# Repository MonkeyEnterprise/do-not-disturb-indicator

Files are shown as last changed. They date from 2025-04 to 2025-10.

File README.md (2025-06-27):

<!-- PROJECT LOGO -->
<div align="center">
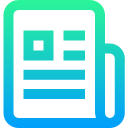
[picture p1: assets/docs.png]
    
<h3 align="center">00.25.0029 - Do Not Disturb Indicator</h3>
</div>
<!-- ABOUT THE PROJECT -->

### About The Project

---

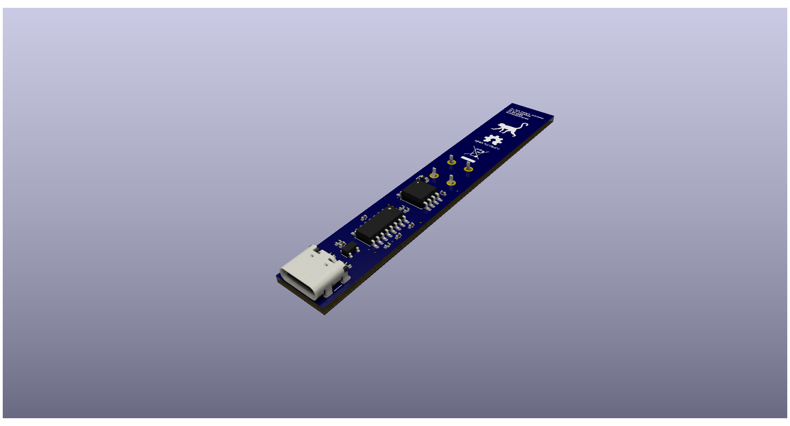
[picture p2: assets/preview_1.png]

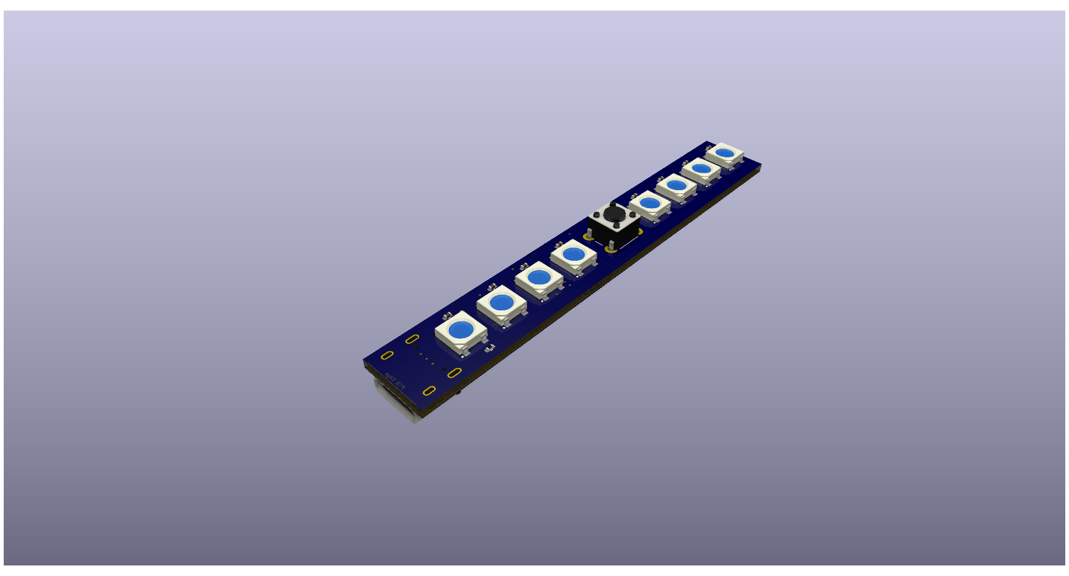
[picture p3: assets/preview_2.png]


This repository provides a comprehensive system to control an WS2812B LED using an ATTINY-85. It includes PCB files, 3D print files, firmware, and software for setting up and operating the system. The firmware implements a serial communication protocol for sending color and brightness commands to the WS2812B LED, using a packet structure with error-checking mechanisms. This setup allows for easy integration and customization of the do not disturb sign.

<!-- BUILD WITH -->
### Built With

* 
* 
* 
* 

<!-- LICENSE -->
### License

---
See `LICENSE` for more information.

<!-- MARKDOWN LINKS & IMAGES -->
<!-- https://www.markdownguide.org/basic-syntax/#reference-style-links -->
[KiCad]: https://img.shields.io/badge/KiCad-3F7D1F?style=for-the-badge&logoColor=white&labelColor=3F7D1F
[VSCode]: https://img.shields.io/badge/VSCode-007ACC?style=for-the-badge&logoColor=white&labelColor=007ACC
[Visual Studio]: https://img.shields.io/badge/Visual_Studio-5C2D91?style=for-the-badge&logoColor=white&labelColor=5C2D91
[SimulIDE]: https://img.shields.io/badge/SimulIDE-0094B3?style=for-the-badge&logoColor=white&labelColor=0094B3

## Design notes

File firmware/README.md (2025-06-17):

# Serial Protocol Documentation

This document describes the serial protocol used to communicate with the NeoPixel controller firmware (`Main.cpp`). The protocol is designed for robust communication, including error checking via CRC, and supports commands for setting colors, changing modes, and querying the current state.

## Protocol Structure

Each command sent to the device must be **9 bytes** long and follow this structure:

| Byte Index | Name | Description | Value Range |
|---|---|---|---|
| 0 | SOF | Start of Frame | `0x01` |
| 1 | Command | Command code (comc) | `0x01` - `0x05`  |
| 2 | Command Val  | Command value (comv), e.g. mode | `0x00` - `0x02`  |
| 3 | Red | Red component | `0x00` - `0xFF`  |
| 4 | Green | Green component | `0x00` - `0xFF`  |
| 5 | Blue | Blue component | `0x00` - `0xFF`  |
| 6 | Brightness | Brightness | `0x00` - `0xFF`  |
| 7 | CRC | Checksum: sum of bytes 1-6, modulo 256 | |
| 8 | EOF | End of Frame | `0x01` |

**CRC Calculation:**  
`CRC = (Command + Command Val + Red + Green + Blue + Brightness) % 256`

## Command Codes

| Code | Name | Description |
|---|---|---|
| 0x01 | Set Color | Set the current color and brightness |
| 0x02 | Clear | Clear the LED strip |
| 0x03 | Set Mode | Change the active mode (0, 1, or 2) |
| 0x04 | Store Color  | Store color and brightness for current mode |
| 0x05 | Get Color | Query the current color and brightness |

## Example Commands

### 1. Set Color (Red, mode 0, brightness 255)

- **Command:** Set color to red, mode 0, brightness 255  
- **Fields:** SOF=01, Command=01, Command Val=00, R=FF, G=00, B=00, Brightness=FF  
- **CRC:** (01 + 00 + FF + 00 + 00 + FF) % 256 = 0x01 + 0x00 + 0xFF + 0x00 + 0x00 + 0xFF = 0x1FF, 0x1FF % 256 = 0xFF  
- **Bytes:** `01 01 00 FF 00 00 FF FF 01`

### 2. Store Color (Green, mode 1, brightness 128)

- **Command:** Store color green for mode 1, brightness 128  
- **Fields:** SOF=01, Command=04, Command Val=01, R=00, G=FF, B=00, Brightness=80  
- **CRC:** (04 + 01 + 00 + FF + 00 + 80) % 256 = 0x184, 0x184 % 256 = 0x84  
- **Bytes:** `01 04 01 00 FF 00 80 84 01`

### 3. Set Mode (mode 2)

- **Command:** Set mode to 2  
- **Fields:** SOF=01, Command=03, Command Val=02, R=00, G=00, B=00, Brightness=00  
- **CRC:** (03 + 02 + 00 + 00 + 00 + 00) % 256 = 0x05  
- **Bytes:** `01 03 02 00 00 00 00 05 01`

### 4. Get Color (for current mode)

- **Command:** Get color for current mode  
- **Fields:** SOF=01, Command=05, Command Val=00, R=00, G=00, B=00, Brightness=00  
- **CRC:** (05 + 00 + 00 + 00 + 00 + 00) % 256 = 0x05  
- **Bytes:** `01 05 00 00 00 00 00 05 01`

### 5. Clear LEDs

- **Command:** Clear the LED strip  
- **Fields:** SOF=01, Command=02, Command Val=00, R=00, G=00, B=00, Brightness=00  
- **CRC:** (02 + 00 + 00 + 00 + 00 + 00) % 256 = 0x02  
- **Bytes:** `01 02 00 00 00 00 00 02 01`

## Error Codes

The device responds with a response code indicating the result:

| Code | Meaning |
|---|---|
| 0x0  | Success |
| 0x1  | Start of Frame error |
| 0x2  | Command error |
| 0x3  | Command value error |
| 0x4  | CRC error |
| 0x5  | End of Frame error |

---

For more details, see the implementation in `Main.cpp`.

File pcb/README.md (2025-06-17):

This directory is intended for the project pcb.

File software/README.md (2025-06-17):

# NeoPixel Status Tray Application

A Windows system tray application for controlling a NeoPixel device via serial port.  
Easily set your status (Do Not Disturb, Busy, Available, Off), adjust brightness, and customize colors.

## Features

- System tray icon with status indicator
- Selectable statuses: Do Not Disturb, Busy, Available, Off
- Adjustable brightness (Dimmer, Normal, Brighter)
- Custom color picker for each status
- COM port selection menu
- Settings saved to `settings.json`
- Logging to `main.log` and console

## Requirements

- Python 3.13+
- [pyserial](https://pypi.org/project/pyserial/)
- [pystray](https://pypi.org/project/pystray/)
- [Pillow](https://pypi.org/project/Pillow/)

Install dependencies with:

```sh
pip install -r requirements.txt
```

## Usage

1. Connect your NeoPixel device to a serial port.
2. Run the application:
3. Use the tray icon to select your COM port and control the device.

## Project Structure

- `main.py` — Application entry point
- `source/toolbar_menu.py` — Main tray menu logic
- `source/serial_controller.py` — Serial port communication
- `source/protocol.py` — Protocol for device commands
- `source/icon_creator.py` — Icon image generation
- `source/settings_manager.py` — Settings load/save logic

## Settings

Settings are stored in `settings.json` and include:

- Colors for each status
- Last used COM port
- Brightness factor

## Logging

Logs are written to `main.log` and the console for troubleshooting.

---

*Developed for NeoPixel status indication via system tray.*

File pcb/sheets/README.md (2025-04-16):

This directory is intended for the project pcb pages.

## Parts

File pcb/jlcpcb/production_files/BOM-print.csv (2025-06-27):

Comment | Designator | Footprint | LCSC | Quantity
PRTR5V0U2X | D1 | SOT-143 | C12333 | 1
100nF | C1,C10,C11,C12,C13,C2,C3,C4,C6,C7,C8,C9 | C_0402_1005Metric | C1525 | 12
4.7nF/1kV | C5 | C_0402_1005Metric | C1538 | 1
CPU | D2 | D_0603_1608Metric | C2286 | 1
1K0 | R1,R4,R5,R7 | R_0402_1005Metric | C25744 | 4
4K7 | R6 | R_0402_1005Metric | C25900 | 1
5K1 | R2,R3 | R_0402_1005Metric | C25905 | 2
1M0 | R8 | R_0402_1005Metric | C26083 | 1
USB_C_Receptacle_USB2.0_16P | J1 | USB_C_Receptacle_GCT_USB4105-xx-A_16P_TopMnt_Horizontal | C2765186 | 1
WS2812B | D10,D3,D4,D5,D6,D7,D8,D9 | LED_WS2812B_PLCC4_5.0x5.0mm_P3.2mm | C2843785 | 8
ATtiny85-20S | U1 | SOIC-8_5.3x5.3mm_P1.27mm | C31540447 | 1
CH340C | U2 | SOIC-16_3.9x9.9mm_P1.27mm | C84681 | 1

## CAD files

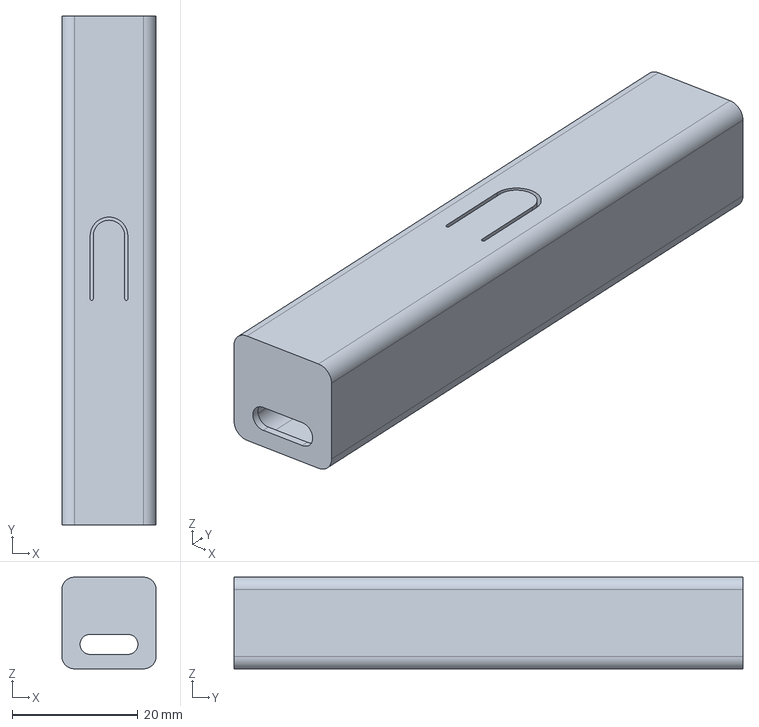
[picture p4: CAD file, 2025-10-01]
models/model.FCStd
15.0 x 81.0 x 14.6 mm

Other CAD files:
models/model.3mf
models/model.stl

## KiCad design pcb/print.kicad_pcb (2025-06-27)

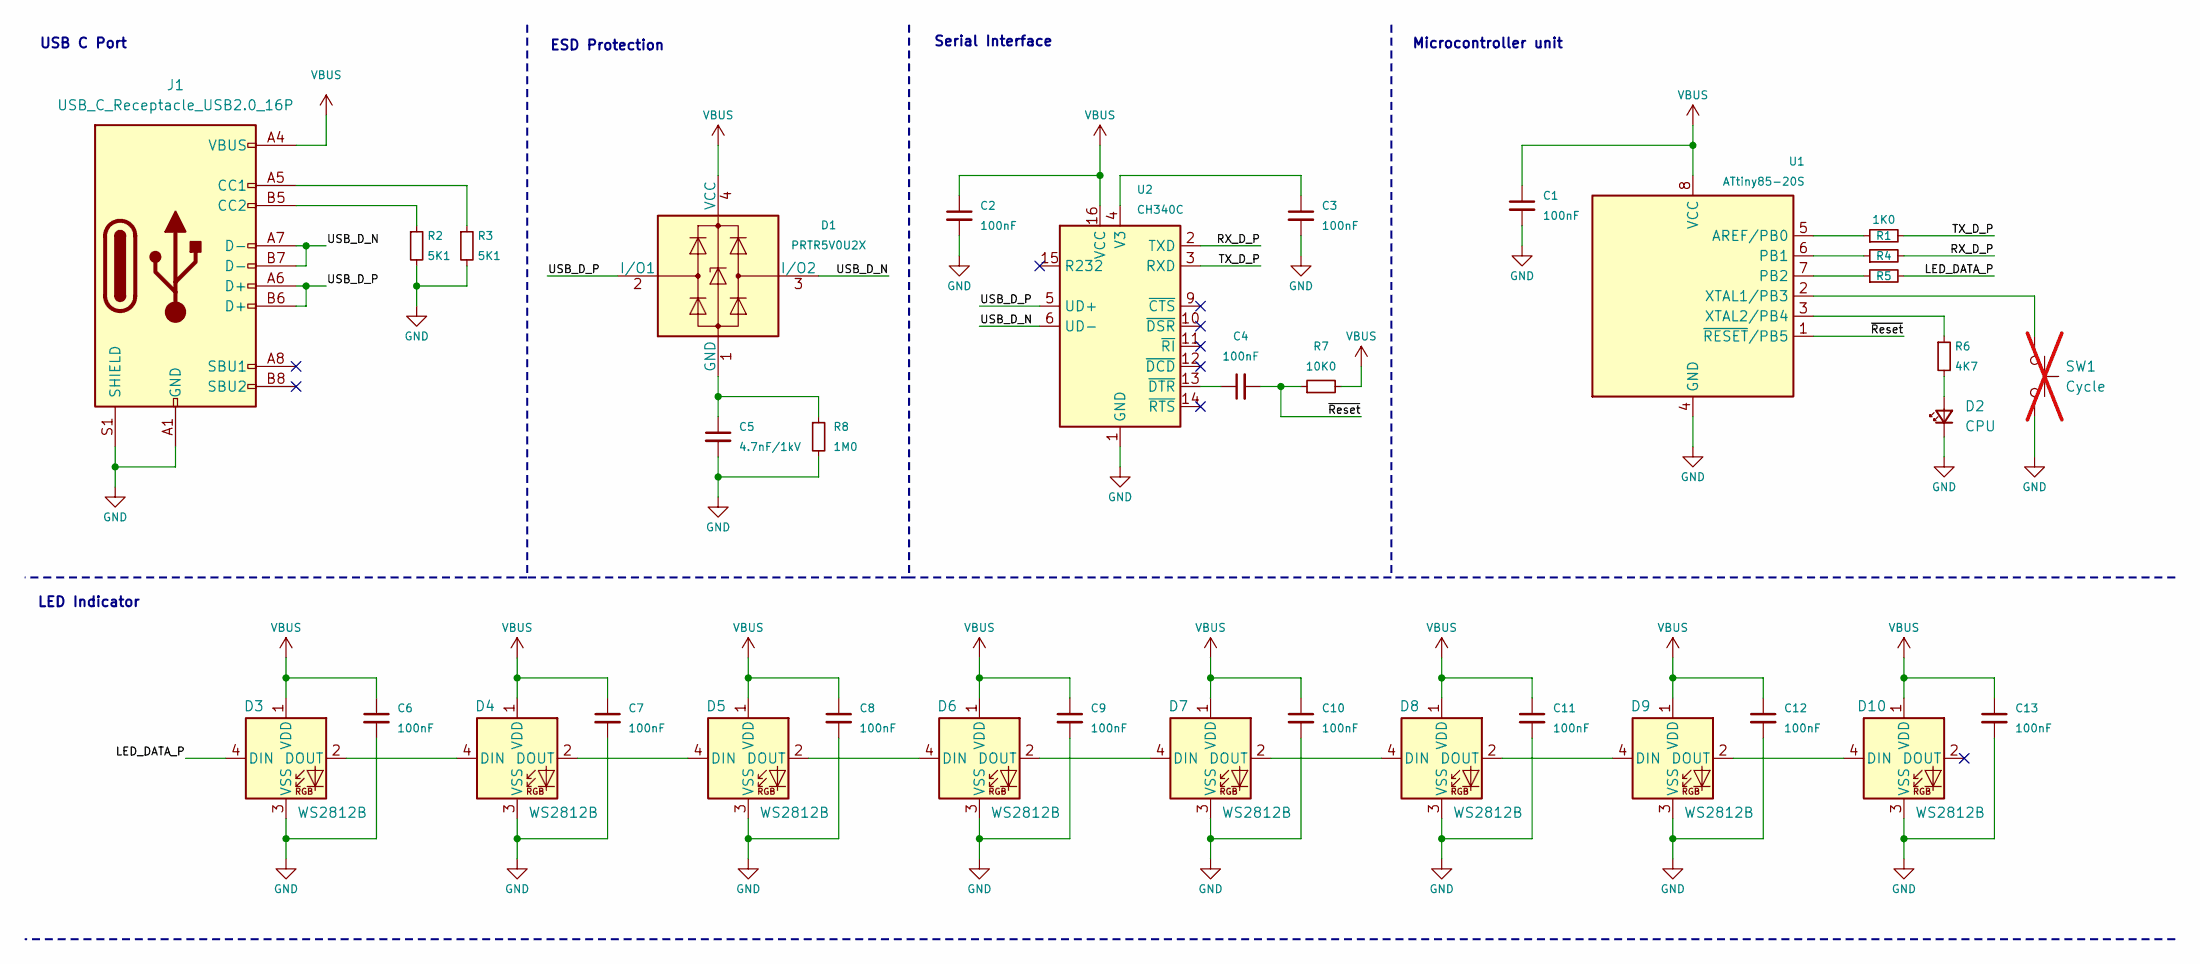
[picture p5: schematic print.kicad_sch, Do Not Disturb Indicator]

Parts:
C1, C2, C3, C4, C6, C7, C8, C9, C10, C11, C12, C13: 100nF; C_0402_1005Metric; LCSC C1525
C5: 4.7nF/1kV; C_0402_1005Metric; LCSC C1538
D1: PRTR5V0U2X; SOT-143; LCSC C12333
D2: CPU; D_0603_1608Metric; LCSC C2286
D3, D4, D5, D6, D7, D8, D9, D10: WS2812B; LED_WS2812B_PLCC4_5.0x5.0mm_P3.2mm; LCSC C2843785
J1: USB_C_Receptacle_USB2.0_16P; USB_C_Receptacle_GCT_USB4105-xx-A_16P_TopMnt_Horizontal; LCSC C2765186
R1, R4, R5: 1K0; R_0402_1005Metric; LCSC C25744
R2, R3: 5K1; R_0402_1005Metric; LCSC C25905
R6: 4K7; R_0402_1005Metric; LCSC C25900
R7: 10K0; R_0402_1005Metric; LCSC C25744
R8: 1M0; R_0402_1005Metric; LCSC C26083
SW1: Cycle; SW_PUSH_6mm_H4.3mm; not fitted
U1: ATtiny85-20S; SOIC-8_5.3x5.3mm_P1.27mm; LCSC C31540447
U2: CH340C; SOIC-16_3.9x9.9mm_P1.27mm; LCSC C84681

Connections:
/LED_DATA_P: D3.4 (DIN), R5.2
/RX_D_P: R4.2, U2.2 (TXD)
/TX_D_P: R1.2, U2.3 (RXD)
/USB_D_N: D1.3 (I/O2), J1.A7 (D-), J1.B7 (D-), U2.6 (UD-)
/USB_D_P: D1.2 (I/O1), J1.A6 (D+), J1.B6 (D+), U2.5 (UD+)
/~Reset: C4.2, R7.1, U1.1 (~RESET/PB5)
GND: C1.2, C2.2, C3.2, C5.2, C6.2, C7.2, C8.2, C9.2, C10.2, C11.2, C12.2, C13.2, D2.1 (K), D3.3 (VSS), D4.3 (VSS), D5.3 (VSS), D6.3 (VSS), D7.3 (VSS), D8.3 (VSS), D9.3 (VSS), D10.3 (VSS), J1.A1 (GND), J1.A12 (GND), J1.B1 (GND), J1.B12 (GND), J1.S1 (SHIELD), R2.2, R3.2, R8.2, SW1.2, U1.4 (GND), U2.1 (GND)
unnamed: C5.1, D1.1 (GND), R8.1
unnamed: D2.2 (A), R6.2
unnamed: D3.2 (DOUT), D4.4 (DIN)
unnamed: D4.2 (DOUT), D5.4 (DIN)
unnamed: D5.2 (DOUT), D6.4 (DIN)
unnamed: D6.2 (DOUT), D7.4 (DIN)
unnamed: D7.2 (DOUT), D8.4 (DIN)
unnamed: D8.2 (DOUT), D9.4 (DIN)
unnamed: D9.2 (DOUT), D10.4 (DIN)
unnamed: J1.A5 (CC1), R3.1
unnamed: J1.B5 (CC2), R2.1
unnamed: R1.1, U1.5 (AREF/PB0)
unnamed: R4.1, U1.6 (PB1)
unnamed: R5.1, U1.7 (PB2)
unnamed: SW1.1, U1.2 (XTAL1/PB3)
unnamed: R6.1, U1.3 (XTAL2/PB4)
unnamed: C3.1, U2.4 (V3)
unnamed: C4.1, U2.13 (~DTR)
VBUS: C1.1, C2.1, C6.1, C7.1, C8.1, C9.1, C10.1, C11.1, C12.1, C13.1, D1.4 (VCC), D3.1 (VDD), D4.1 (VDD), D5.1 (VDD), D6.1 (VDD), D7.1 (VDD), D8.1 (VDD), D9.1 (VDD), D10.1 (VDD), J1.A4 (VBUS), J1.A9 (VBUS), J1.B4 (VBUS), J1.B9 (VBUS), R7.2, U1.8 (VCC), U2.16 (VCC)

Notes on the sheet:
USB C Port
Microcontroller unit
Serial Interface
LED Indicator
ESD Protection

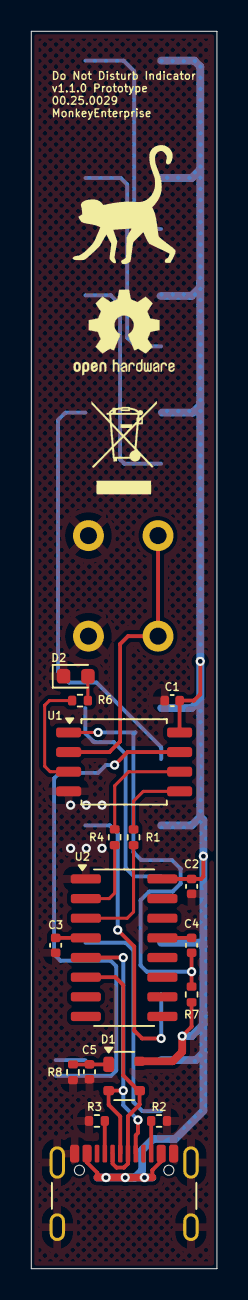
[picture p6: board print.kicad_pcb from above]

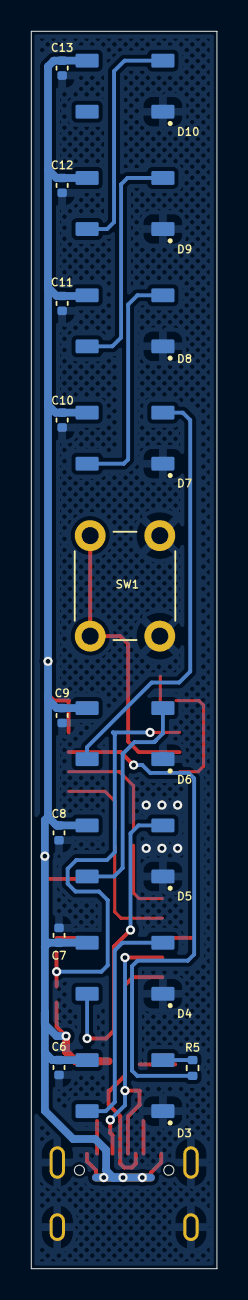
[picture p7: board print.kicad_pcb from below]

Board: 2 copper layers, 12.0 x 80.0 mm, 35 parts (18 on the bottom side), 26 nets.

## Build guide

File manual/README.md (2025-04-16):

This directory is intended for the project manual.

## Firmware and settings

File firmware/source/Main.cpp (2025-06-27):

/**
 * @file Main.cpp
 * @brief Main source file for the device firmware.
 *
 * @copyright (c) 2025 Lorenzo Pouw, PouwerTronics/MonkeyEnterprise.
 * Licensed under the BSD license. This notice must remain in all redistributions.
 */

#include "Main.h"

/**
 * @brief Get the RGB color and brightness values based on the current mode
 * @param red Reference to store the red component (0-255)
 * @param green Reference to store the green component (0-255)
 * @param blue Reference to store the blue component (0-255)
 * @param brightness Reference to store the brightness (0-255)
 */
void getColor(uint8_t &red, uint8_t &green, uint8_t &blue, uint8_t &brightness)
{
    // Define a structure to hold the color reference based on the current mode
    struct ColorRef
    {
        uint8_t &r, &g, &b, &br;
    };

    // Lambda function to get the current color reference based on the mode
    auto getColorRef = [&]() -> ColorRef
    {
        switch (globalVar.mode)
        {
        case 0:
            return {globalVar.red_mode0, globalVar.green_mode0, globalVar.blue_mode0, globalVar.brightness_mode0};
        case 1:
            return {globalVar.red_mode1, globalVar.green_mode1, globalVar.blue_mode1, globalVar.brightness_mode1};
        case 2:
            return {globalVar.red_mode2, globalVar.green_mode2, globalVar.blue_mode2, globalVar.brightness_mode2};
        default:
            return {globalVar.red_mode0, globalVar.green_mode0, globalVar.blue_mode0, globalVar.brightness_mode0};
        }
    };

    // Get the current color based on the mode
    ColorRef color = getColorRef();

    red = color.r;
    green = color.g;
    blue = color.b;
    brightness = color.br;
}

/**
 * @brief Store the RGB color and brightness values in the global variable based on the current mode
 * @param red The red component of the color (0-255)
 * @param green The green component of the color (0-255)
 * @param blue The blue component of the color (0-255)
 * @param brightness The brightness of the color (0-255)
 */
void storeColor(uint8_t red, uint8_t green, uint8_t blue, uint8_t brightness)
{
    switch (globalVar.mode)
    {
    case 0:
        globalVar.red_mode0 = red;
        globalVar.green_mode0 = green;
        globalVar.blue_mode0 = blue;
        globalVar.brightness_mode0 = brightness;
        break;
    case 1:
        globalVar.red_mode1 = red;
        globalVar.green_mode1 = green;
        globalVar.blue_mode1 = blue;
        globalVar.brightness_mode1 = brightness;
        break;
    case 2:
        globalVar.red_mode2 = red;
        globalVar.green_mode2 = green;
        globalVar.blue_mode2 = blue;
        globalVar.brightness_mode2 = brightness;
        break;
    default:
        break;
    };

    cfgReg.save(globalVar);
}

/**
 * @brief Set the color of the NeoPixel LEDs based on the current mode
 */
void setColor()
{
    uint8_t red, green, blue, brightness;
    getColor(red, green, blue, brightness);
    pixel.setBrightness(brightness);
    pixel.fill(pixel.Color(red, green, blue));
    pixel.show();
}

/**
 * @brief Flush the receive buffer to clear any pending data
 */
void flushReceiveBuffer()
{
    // Flush the receive buffer to clear any pending data
    while (tinySerial.available())
    {
        tinySerial.read();
    }
}

/**
 * @brief Send a response back to the serial interface, including a CRC for error checking
 * @param responseCode The response code to be sent.
 * @param comc The command value (comc) to be sent (0-255), optional, default is 0x0.
 * @param red The red component of the color to be sent (0-255), optional, default is 0x0.
 * @param green The green component of the color to be sent (0-255), optional, default is 0x0.
 * @param blue The blue component of the color to be sent (0-255), optional, default is 0x0.
 * @param brightness The brightness of the color to be sent (0-255), optional, default is 0x0.
 */
void sendResponse(const uint8_t responseCode,
                  const uint8_t comc = 0x0,
                  const uint8_t red = 0x0,
                  const uint8_t green = 0x0,
                  const uint8_t blue = 0x0,
                  const uint8_t brightness = 0x0)
{
    uint8_t crc = (responseCode + comc + red + green + blue + brightness) % 256;
    tinySerial.write(0x01);         // Start of Frame
    tinySerial.write(responseCode); // Response code
    tinySerial.write(comc);         // Command value (comc)
    tinySerial.write(red);          // Red component
    tinySerial.write(green);        // Green component
    tinySerial.write(blue);         // Blue component
    tinySerial.write(brightness);   // Brightness
    tinySerial.write(crc);          // CRC
    tinySerial.write(0x01);         // End of Frame
    tinySerial.flush();             // Ensure all data is sent
    flushReceiveBuffer(); // Clear the receive buffer after sending
}

/**
 * @brief Handle the command received from the serial interface
 * @param data Pointer to the command data
 * @return Response code indicating success or error
 *
 * @note The error codes are as follows:
 * 0x0 - Success
 * 0x1 - Start of Frame (SOF) error
 * 0x2 - Command (coma) error
 * 0x3 - Command value (comc) error
 * 0x4 - CRC error
 * 0x5 - End of Frame (EOF) error
 */
uint8_t handleCommand(const uint8_t *data)
{
    // Check if the start of frame (SOF) is correct and validate the command structure
    const uint8_t sof = data[0];
    if (sof != 0x1)
        return 0x1;

    // Validate the command (coma), which should be between 1 and 5
    const uint8_t coma = data[1];
    if (coma > 5)
        return 0x2;

    // Validate the command value (comc), which should be between 0 and 2
    const uint8_t comc = data[2];
    if (comc > 2)
        return 0x3;

    // Validate the RGB color components and brightness
    const uint8_t red = data[3];
    const uint8_t green = data[4];
    const uint8_t blue = data[5];
    const uint8_t brightness = data[6];

    // validate the CRC calculation
    const uint8_t crc = data[7];
    const uint8_t crcCalc = (coma + comc + red + green + blue + brightness) % 256;
    if (crc != crcCalc)
        return 0x4;

    // Check if the end of frame (EOF) is correct
    const uint8_t eof = data[8];
    if (eof != 0x1)
        return 0x5;

    // If all checks passed, return success
    return 0x0;
}

/**
 * @brief Setup function to initialize the serial communication, NeoPixel strip, and global variables
 */
void setup()
{
    // Initialize the serial communication with the specified baud rate
    tinySerial.begin(BAUD_RATE);

    flushReceiveBuffer();

    // Initialize the global variable with default configuration
    GlobalVar temp = cfgReg.load(defaultCfg);
    if (temp.config_version != defaultCfg.config_version)
    {
        globalVar = defaultCfg;
        cfgReg.wipeEEPROM();
        cfgReg.save(globalVar);
    }
    else
        globalVar = temp;

    // Initialize the pixel strip
    pixel.begin();
    setColor();
    cpuLed.enableBlink(500);
}

/**
 * @brief Main loop function that continuously checks for button presses and serial commands
 */
void loop()
{
    // Update the cycle button state and check if it was pressed
    cycleButton.update();
    if (cycleButton.fell())
    {
        globalVar.mode = (globalVar.mode + 1) % 3;
        cfgReg.save(globalVar);
        setColor();
    }

    // Check if there are enough bytes available in the serial buffer to read a command
    // The command should be 9 bytes long: SOF (1 byte) + coma (1 byte) + comc (1 byte) + RGB (3 bytes) + brightness (1 byte) + CRC (1 byte) + EOF (1 byte)
    // If there are enough bytes, read the command and handle it
    if (tinySerial.available() == 9)
    {
        uint8_t data[9];
        tinySerial.readBytes(data, 9);

        const uint8_t responseCode = handleCommand(data);

        if (responseCode == 0x0)
        {
            const uint8_t coma = data[1];
            const uint8_t comc = data[2];
            const uint8_t red = data[3];
            const uint8_t green = data[4];
            const uint8_t blue = data[5];
            const uint8_t brightness = data[6];

            switch (coma)
            {
            // Set color command
            case 0x01:
                setColor();
                sendResponse(0x0); // Success response
                break;
            // Clear the pixel strip
            case 0x02:
                pixel.clear();
                pixel.show();
                sendResponse(0x0); // Success response
                break;
            // Set mode command
            case 0x03:
                globalVar.mode = comc;
                cfgReg.save(globalVar);
                setColor();
                sendResponse(0x0); // Success response
                break;
            // Store color command
            case 0x04:
                storeColor(red, green, blue, brightness);
                sendResponse(0x0); // Success response
                break;
            // Get color command
            case 0x05:
                uint8_t cureRed, currentGreen, currentBlue, currentBrightness;
                getColor(cureRed, currentGreen, currentBlue, currentBrightness);
                sendResponse(0x0, globalVar.mode, cureRed, currentGreen, currentBlue, currentBrightness);
                break;
            // Invalid command, this should not happen, just in case send an error response
            default:
                sendResponse(0x2); // Invalid command
                break;
            }
        }
    }
    cpuLed.update();
}

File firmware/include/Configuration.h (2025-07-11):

/**
 * @file Configuration.h
 * @brief Configuration header file for the device firmware.
 *
 * @copyright (c) 2025 Lorenzo Pouw, PouwerTronics/MonkeyEnterprise.
 * Licensed under the BSD license. This notice must remain in all redistributions.
 */

#ifndef __CONFIGURATION_H__
#define __CONFIGURATION_H__

#include <Arduino.h>
#include <Adafruit_NeoPixel.h>

// Define the CPU frequency for the AVR microcontroller
// ------- Hardware Configuration -------
#define TX_PIN PB0
#define RX_PIN PB1
#define LED_PIN PB2
#define CPU_PIN PB4
#define BUTTON_PIN PB3

// ------- Software Configuration -------
#define BAUD_RATE 9600
#define LED_COUNT 8
#define LED_TYPE NEO_GRB + NEO_KHZ800

// ------- Global Variables -------
struct GlobalVar
{
    uint8_t config_version;
    uint8_t mode;
    uint8_t red_mode0, green_mode0, blue_mode0, brightness_mode0;
    uint8_t red_mode1, green_mode1, blue_mode1, brightness_mode1;
    uint8_t red_mode2, green_mode2, blue_mode2, brightness_mode2;
};

const GlobalVar defaultCfg = {
    1,               // config_version
    0,               // mode
    255, 0, 0, 255,  // mode 0: red, green, blue, brightness
    0, 255, 0, 255,  // mode 1: red, green, blue, brightness
    255, 255, 0, 255 // mode 2: red, green, blue, brightness
};

#endif // __CONFIGURATION_H__

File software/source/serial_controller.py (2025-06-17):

# software/source/serial_controller.py
import logging
import serial
import serial.tools.list_ports
from typing import List, Tuple, Optional

# Assuming Protocol is defined in ./protocol.py
from .protocol import Protocol 

class SerialController:
    """
    @brief Manages serial communication with a device.

    Handles port discovery, connection, disconnection, and sending commands.
    """

    def __init__(self, protocol: Protocol, baudrate: int):
        """
        @brief Initializes the SerialController.

        @param protocol: An instance of the Protocol class for command creation.
        @type protocol: Protocol
        @param baudrate: The baud rate for serial communication.
        @type baudrate: int
        """
        self._protocol = protocol
        self._baudrate = baudrate
        self._serial_port: Optional[serial.Serial] = None  # Holds the pyserial Serial object
        self._selected_port_device: Optional[str] = None # Stores the device name, e.g., 'COM3'

    @property
    def selected_port(self) -> Optional[str]:
        """
        @brief Get the currently selected COM port device name.

        @return: The selected COM port device name, or None if not set.
        @rtype: str | None
        """
        return self._selected_port_device

    @selected_port.setter
    def selected_port(self, port_device: Optional[str]) -> None:
        """
        @brief Set the COM port device name.

        Note: Setting this property does not automatically connect. Call connect() explicitly.

        @param port_device: The COM port device name (e.g., 'COM3', '/dev/ttyUSB0').
        @type port_device: str | None
        @return: None
        """
        self._selected_port_device = port_device

    @property
    def is_connected(self) -> bool:
        """
        @brief Checks if the serial port is currently open and connected.

        @return: True if connected, False otherwise.
        @rtype: bool
        """
        return self._serial_port is not None and self._serial_port.is_open

    def connect(self) -> bool:
        """
        @brief Attempts to open the selected serial port.

        If a port is already open, it will be closed first.
        Sets self._serial_port to the pyserial Serial object on success.

        @return: True if connection was successful, False otherwise.
        @rtype: bool
        """
        if self._serial_port and self._serial_port.is_open:
            self.close_port() # Ensure any existing open port is closed

        if not self._selected_port_device:
            logging.warning("No COM port selected to connect.")
            return False

        try:
            logging.info(f"Attempting to open serial port: {self._selected_port_device} at {self._baudrate} baud.")
            # Timeout for reading: set to a small value, e.g., 1 second
            self._serial_port = serial.Serial(self._selected_port_device, self._baudrate, timeout=1)
            # You might want to send a handshake command here and read a response
            # to verify the device is responsive.
            return True
        except serial.SerialException as e:
            logging.error(f"Could not open serial port {self._selected_port_device}: {e}")
            self._serial_port = None  # Ensure it's None on failure
            return False
        except Exception as e:
            logging.error(f"An unexpected error occurred during serial connection: {e}", exc_info=True)
            self._serial_port = None
            return False

    def close_port(self) -> None:
        """
        @brief Closes the currently open serial port, if any.

        @return: None
        """
        if self._serial_port and self._serial_port.is_open:
            logging.info(f"Closing serial port: {self._selected_port_device}")
            try:
                self._serial_port.close()
            except serial.SerialException as e:
                logging.error(f"Error closing serial port {self._selected_port_device}: {e}")
            finally:
                self._serial_port = None
        elif self._serial_port: # Port object exists but isn't open (e.g., failed connect)
            self._serial_port = None


    def send_command(self, command_bytes: List[int], expect_response_bytes: int = 0) -> Optional[bytes]:
        """
        @brief Sends a list of integer bytes as a command over the serial port.
               Optionally reads a response after sending.

        Logs a warning if the port is not connected.

        @param command_bytes: A list of integers representing bytes to send.
        @type command_bytes: List[int]
        @param expect_response_bytes: Number of bytes to read as a response. If 0, no response is read.
        @type expect_response_bytes: int
        @return: The received bytes response, or None if no response expected/received/error.
        @rtype: bytes | None
        """
        if self._serial_port and self._serial_port.is_open:
            try:
                # Convert list of ints to bytes object for pyserial
                self._serial_port.write(bytes(command_bytes))
                logging.debug(f"Sent: {command_bytes}") # Useful for debugging serial communication
                
                if expect_response_bytes > 0:
                    # Read the specified number of bytes. This will block up to `timeout` if no data.
                    response = self._serial_port.read(expect_response_bytes)
                    logging.debug(f"Received: {response}")
                    # Validate the received response length
                    if len(response) != expect_response_bytes:
                        logging.warning(f"Expected {expect_response_bytes} bytes, but received {len(response)}.")
                        return None # Indicate incomplete response
                    return response
                return None
            except serial.SerialException as e:
                logging.error(f"Error sending command to {self._selected_port_device} or reading response: {e}. Disconnecting.")
                self.close_port() # Assume connection dropped
                return None
            except Exception as e:
                logging.error(f"An unexpected error occurred while sending command or reading response: {e}", exc_info=True)
                self.close_port()
                return None
        else:
            logging.warning("Serial port not connected. Command not sent.")
            return None

    def get_available_ports(self) -> List[Tuple[str, str]]:
        """
        @brief Discovers and returns a list of available serial ports.

        @return: A list of tuples, where each tuple contains (device_name, description).
        @rtype: List[Tuple[str, str]]
        """
        available_ports = []
        for port in serial.tools.list_ports.comports():
            available_ports.append((port.device, port.description))
        return available_ports

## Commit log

2025-05-26 Progress update
    [print.kicad_pcb, print.kicad_sch]
2025-05-26 First production update.
    [print.kicad_pcb, print.kicad_sch]
2025-05-27 Added the firmware.
    [Configuration.h]
2025-06-27 pcb v1.1.0 update
    [BOM-print.csv, Configuration.h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]
2025-07-11 Update config version, ignore .pyc, add log and settings
    Set config_version to 1 in Configuration.h and add '*.pyc' to .gitignore. Added main.log and settings.json files to software directory for application logging and configuration.
    [Configuration.h]
2025-10-01 Add 3D model files and update PCB project
    Added new 3D model files in .3mf, .stl, and .wrl formats for the project enclosure. Updated FreeCAD (.FCStd) and KiCad PCB project files to reflect changes related to the new model integration.
    [model.3mf, model.FCStd, model.stl]
